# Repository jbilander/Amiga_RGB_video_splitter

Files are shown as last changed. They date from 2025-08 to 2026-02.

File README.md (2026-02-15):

# Amiga_RGB_video_splitter
Extend your amiga RGB video signal to two display units - screens, monitors, etc, simultaneously

BOM Rev. C
---------
Reference  | Name/Value   | Package/Footprint | Notes
-|-|-|-|
U1 | THS7374IPWR | TSSOP-14_4.4x5mm_P0.65mm | [THS7374IPWR](https://www.mouser.com/ProductDetail/595-THS7374IPWR)
U2 | 74HCT2G17 | TSOP-6_1.65x3.05mm_P0.95mm | [HCT2G17GV125](https://www.mouser.com/ProductDetail/771-HCT2G17GV125)
U3 | 74HCT2G14 | TSOP-6_1.65x3.05mm_P0.95mm | [HCT2G14GV125](https://www.mouser.com/ProductDetail/771-HCT2G14GV125)
U4 | 74LVC1GX04GV X-TAL DRIVER | TSOP-6_1.65x3.05mm_P0.95mm | [LVC1GX04GV125](https://www.mouser.com/ProductDetail/771-LVC1GX04GV125)
Y1 | 18pF Crystal 28.6363 MHz (NTSC) or 28.375 MHz (PAL) | 3.2 mm x 2.5 mm | [ECS-286.3-18-33-JEM-TR](https://www.mouser.com/ProductDetail/520-286.3-18-33-JEMT) (NTSC)<br /> [ABM8-28.375MHZ-B2-T](https://www.mouser.com/ProductDetail/815-ABM8-28.375-B2-T) (PAL)
J1 | D-SUB DB23| DB23_Female-Connector | [Female 23 PIN DB23](https://www.aliexpress.com/item/1005007020706331.html)
J2 | DSUB-15-HD | HD_Female_Horizontal | [VGA connector](https://www.aliexpress.com/item/1005007383371077.html)
J3 | 9 Pin Mini Din Connector | Right Angle TH Mini Circular DIN Receptacle | [9pin Mini Din](https://www.aliexpress.com/item/1005005737270650.html)
J4 | PJ-320A | DIP 3.5mm Headphone Audio Socket 4Pins Audio interface | [PJ-320A](https://www.aliexpress.com/item/4000661212458.html)
J5 | MSK12D19 | 3Pin Slide Toggle Switch Pitch_2.5mm | [MSK12D19 SMD](https://www.aliexpress.com/item/1005006482584650.html)
J6 | MSK12D19 | 3Pin Slide Toggle Switch Pitch_2.5mm | [MSK12D19 SMD](https://www.aliexpress.com/item/1005006482584650.html)
J7 | Right angle Single-Pin Header | 0.64 mm square pin angled | pin for a flylead back to switchable Agnus pin 41 (or its pad on motherboard, e.g. JP4 on A500 Rev.6A)
JP1 | Solder_Jumper | | Solder Jumper for setting above pin (J7) to either /XCLKEN or OE-signal (inverted /XCLKEN signal).
C1 | 100uF Radial Pitch_2.5mm | Capacitor TH Radial_D5.0mm_P2.50mm | e.g. <br />[ECA-1AM101](https://www.mouser.com/ProductDetail/667-ECE-A0JKA101I) <br />[ECE-A0JKA101I](https://www.mouser.com/ProductDetail/667-ECA-1AM101) <br />Bend down flush to board before soldering
C2-C6 | Ceramic Capacitor 0.1uF = 100nF | 0805 | e.g. [CL21B104KACNFNC](https://www.mouser.com/ProductDetail/187-CL21B104KACNFNC)
C7-C8 | Multilayer Ceramic Capacitors MLCC - 32pF | 0603 | [06031A320FAT2A ](https://www.mouser.com/ProductDetail/581-06031A320FAT2A) for oscillator circuit
RN1-RN2 | 75 Ω RES ARRAY 4 Resistors | 1206 | [CAT16-75R0F4LF](https://www.mouser.com/ProductDetail/652-CAT16-75R0F4LF)
R1 | 330 Ω | 1206 | Series resistor on C-sync line
R2-R4 | 10k Ω | 1206  
R5 | Resistor 2.2M Ω | 0603 | Resistor in oscillator-circuit
R6 | Resistor 1k Ω | 0603 | Resistor in oscillator-circuit
R7 | Resistor 150 Ω | 1206 | Damping resistor for XCLK out to minimize reflections and ringing
Housing | 2 x Plastic Shell Cover | For DB23/DB25 plug | [Aliexpress](https://www.aliexpress.com/item/1005004717091904.html)
4 x PinHeader | PinHeader Board Weight/Level Support | 3-pin 2.54 mm pitch single row | Move the plastic guard to leave ~7.5 mm of pin before soldering in order to hold board in perfect level inside the housing

***

<a href="images/Amiga_RGB_video_splitter_pic1.png">
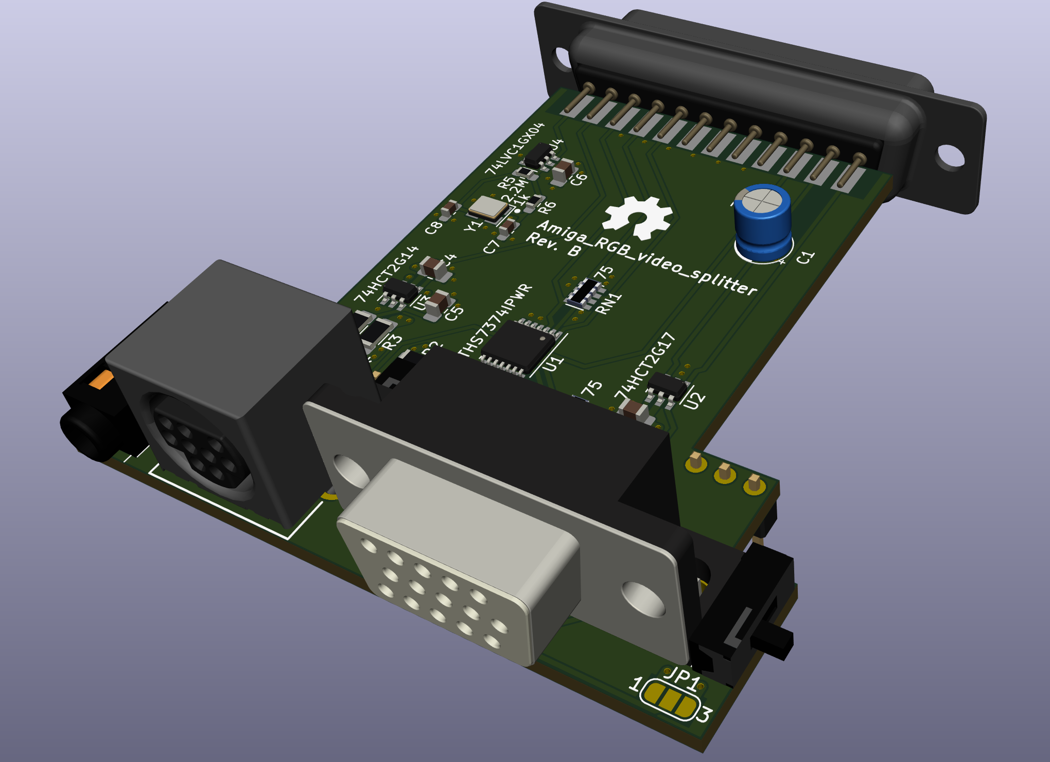
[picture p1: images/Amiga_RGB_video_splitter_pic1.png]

</a>

***

If you use jumper-wire from JP1-pin then you bridge it either with the left pad or the right pad depending on your setup:

    1. Motherboard has PAL oscillator and Adapter has NTSC oscillator = bridge JP1-pin with XCLKEN-pad (PAD 1)
    2. Motherboard has NTSC oscillator and Adapter has PAL oscillator = bridge JP1-pin with OE-pad (PAD 3)

Please note, using a jumper-wire is completely optional, You can switch ECS Agnus in Early Startup menu or with software such as Degrader and then you only control the external XLCK-crystal enable or disable via the switch on the adaptor. However it can be more convenient to have both tasks controlled from one single switch, hence connecting a jumper-wire.

***

<a href="images/SEGA_Mega_Drive_2_SCART_lead_pic1.jpg">
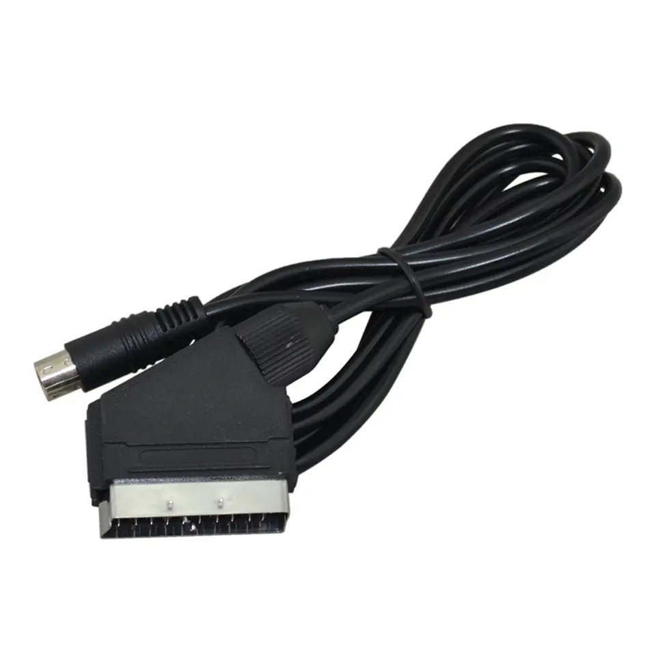
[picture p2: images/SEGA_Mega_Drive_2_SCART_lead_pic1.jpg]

</a>
<a href="images/SEGA_Mega_Drive_2_SCART_lead_wiring.jpg">
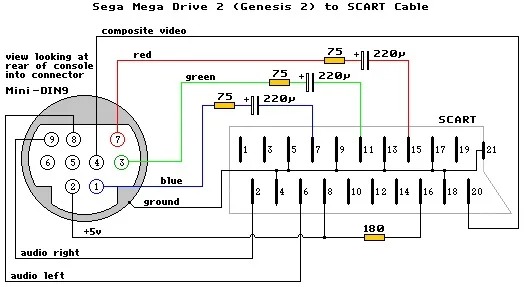
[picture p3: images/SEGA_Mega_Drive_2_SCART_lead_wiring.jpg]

</a>
<br />
<a href="images/SEGA_Mega_Drive_2_SCART_lead_pic2.jpg">
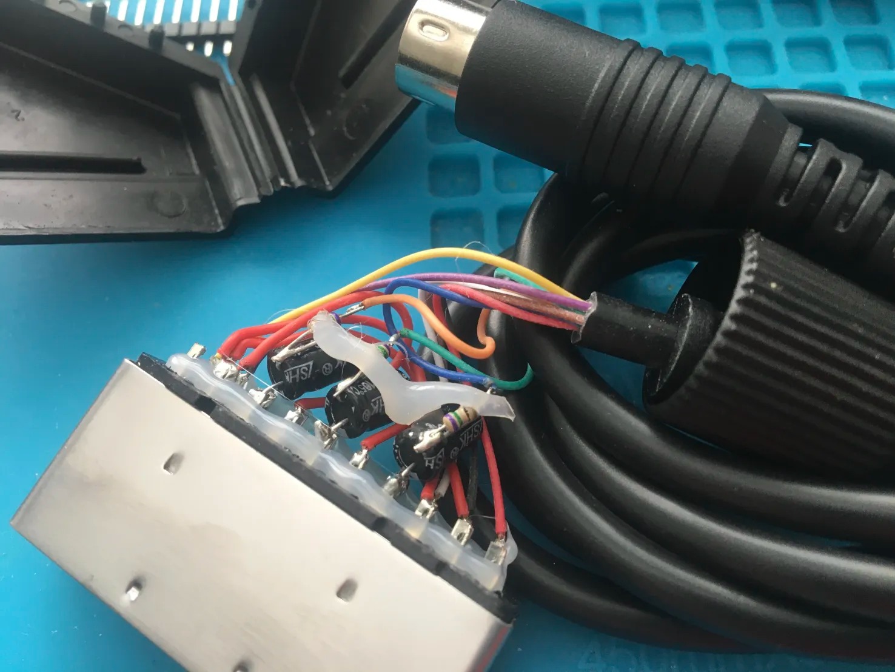
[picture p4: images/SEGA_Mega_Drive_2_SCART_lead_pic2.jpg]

</a>
<a href="images/SEGA_Mega_Drive_2_SCART_lead_pic3.jpg">
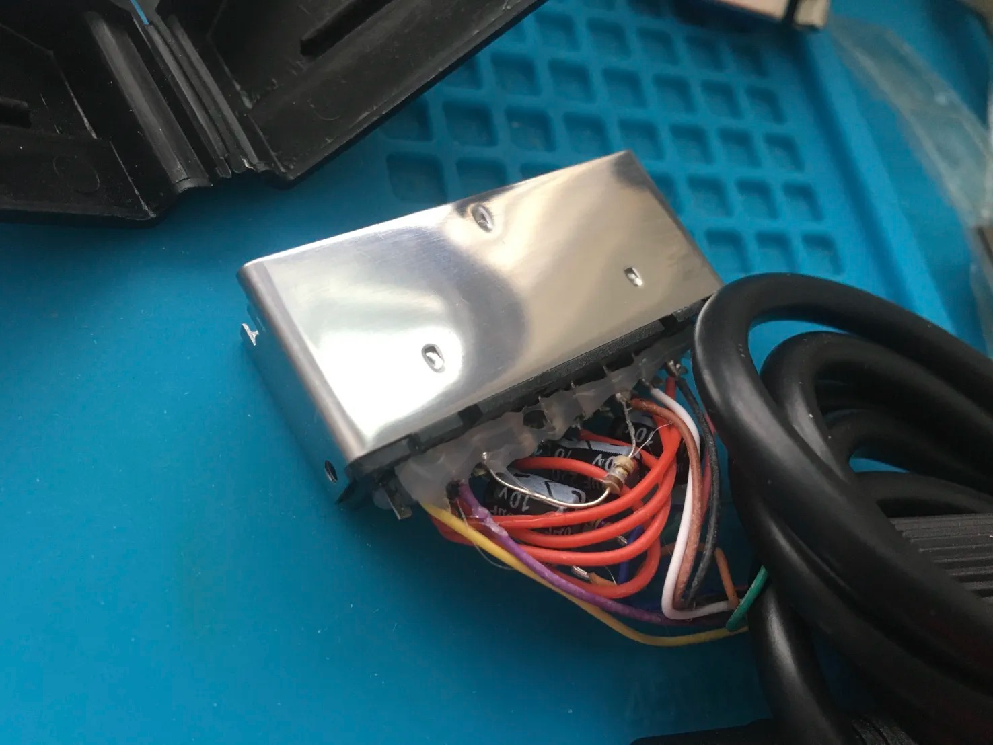
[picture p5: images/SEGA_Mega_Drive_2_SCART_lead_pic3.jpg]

</a>

Suitable SCART-lead to use with the adapter (originally for the SEGA Mega Drive 2, (Genesis 2) with AC coupling inside) <br />
https://www.aliexpress.com/item/1005007360209844.html

***

<a href="images/Amiga_RGB_video_splitter_pic2.jpg">
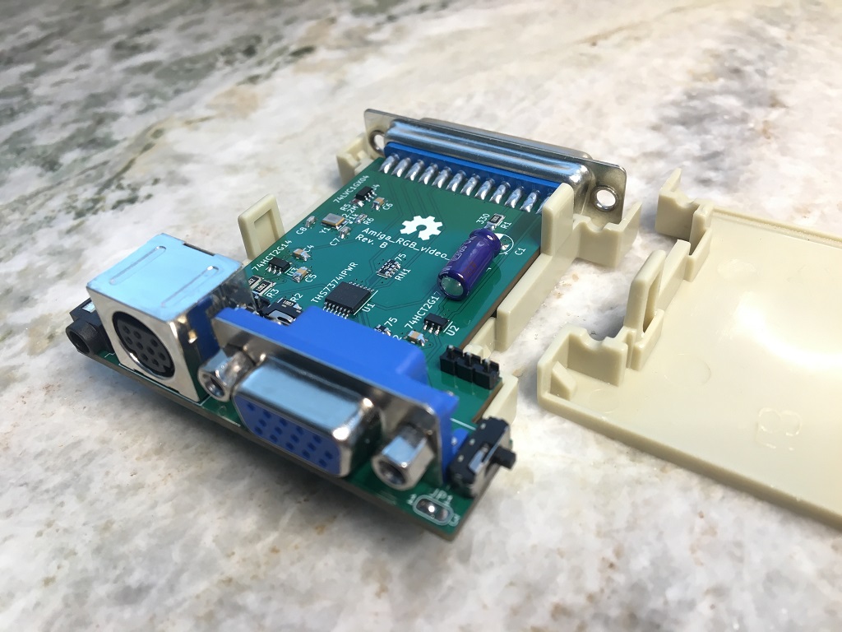
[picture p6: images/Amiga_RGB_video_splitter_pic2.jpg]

</a>
<a href="images/Amiga_RGB_video_splitter_pic3.jpg">
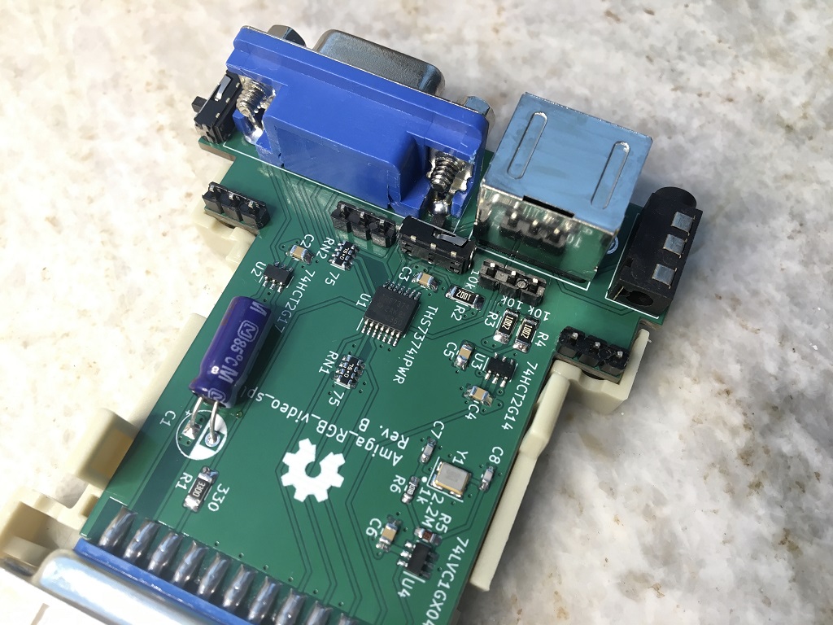
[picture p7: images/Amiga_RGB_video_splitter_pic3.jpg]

</a>
<a href="images/Amiga_RGB_video_splitter_pic4.jpg">
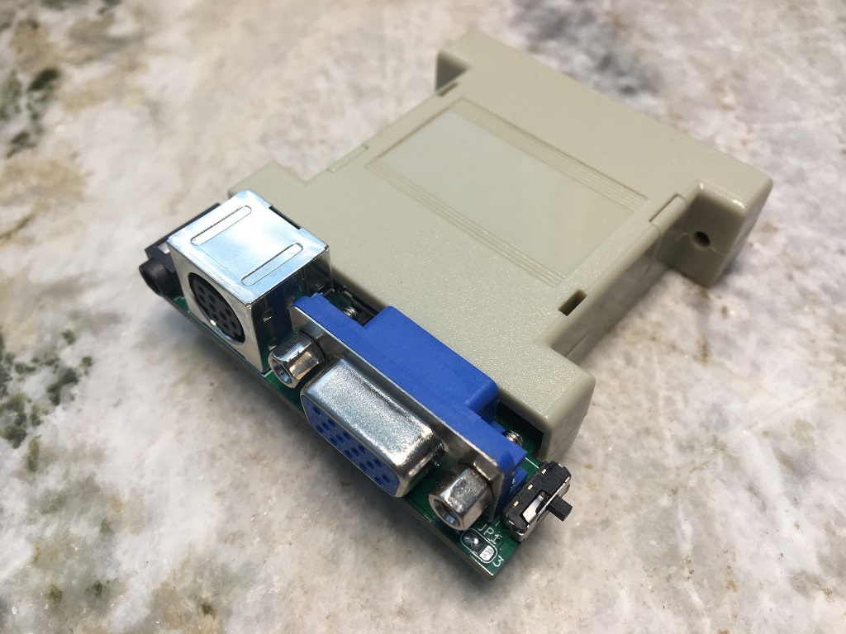
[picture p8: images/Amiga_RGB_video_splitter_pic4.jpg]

</a>
<br />
<a href="images/Amiga_RGB_video_splitter_pic5.jpg">
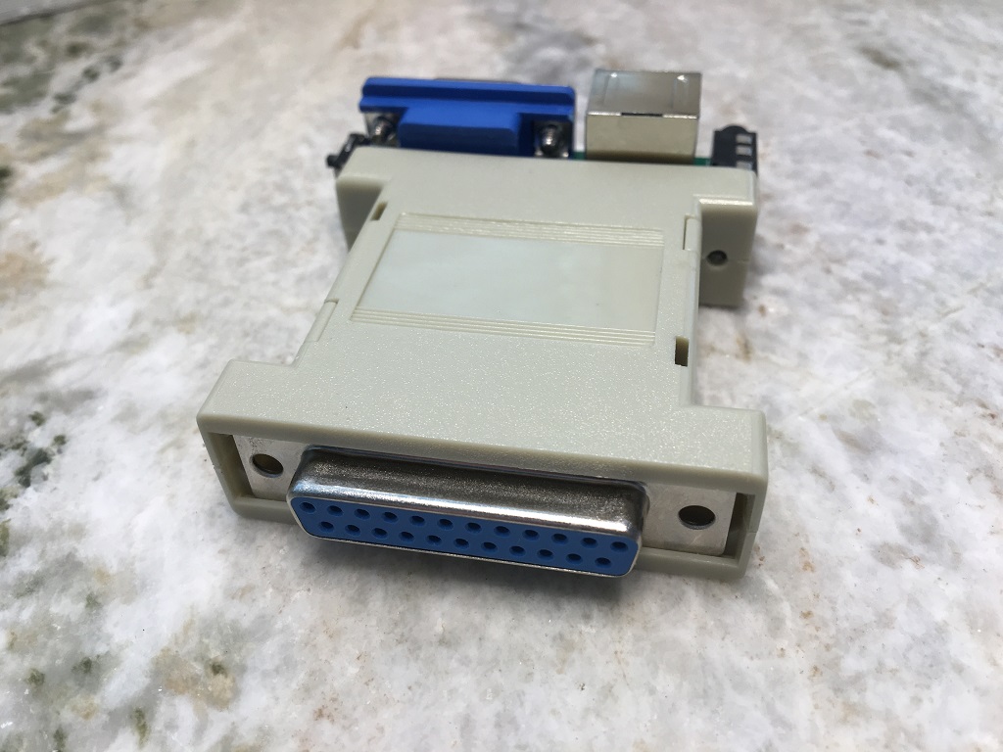
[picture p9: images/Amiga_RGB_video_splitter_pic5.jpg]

</a>
<a href="images/Amiga_RGB_video_splitter_pic6.jpg">
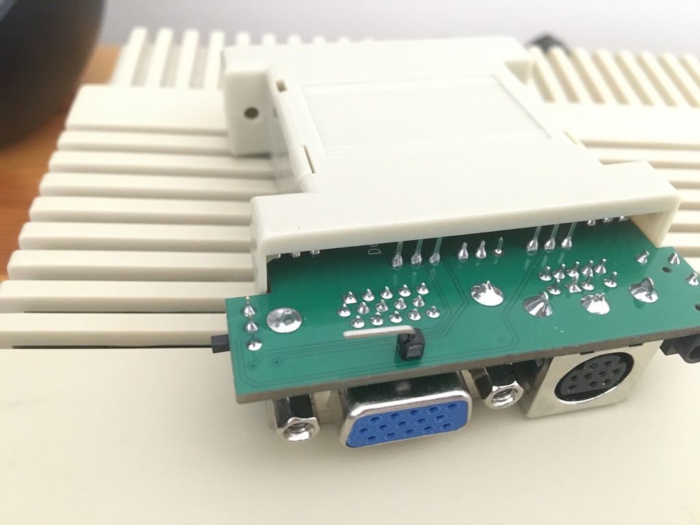
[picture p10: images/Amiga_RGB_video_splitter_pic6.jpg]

</a>
<a href="images/Amiga_RGB_video_splitter_pic7.jpg">
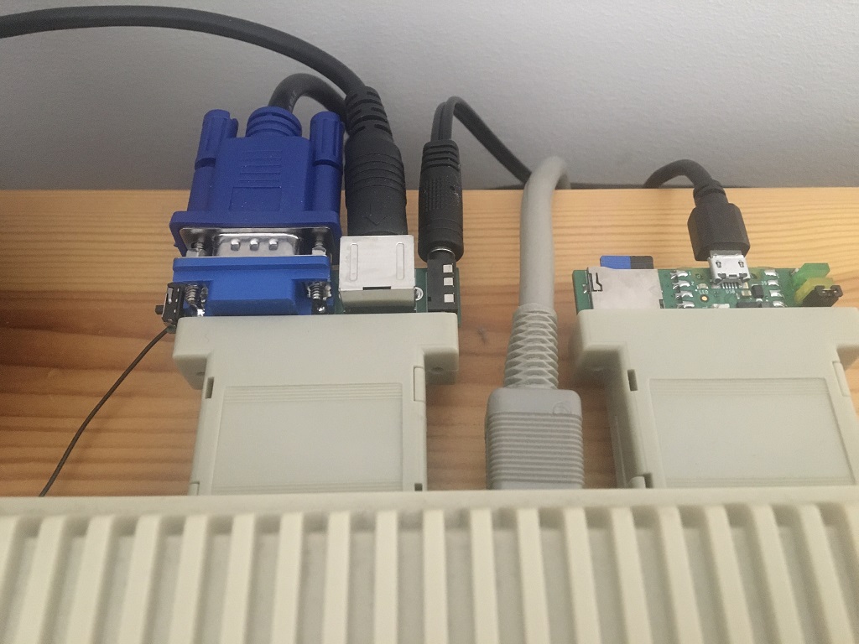
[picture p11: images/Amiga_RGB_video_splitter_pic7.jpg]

</a>
<br />
<a href="images/Amiga_RGB_video_splitter_PCBs.jpg">
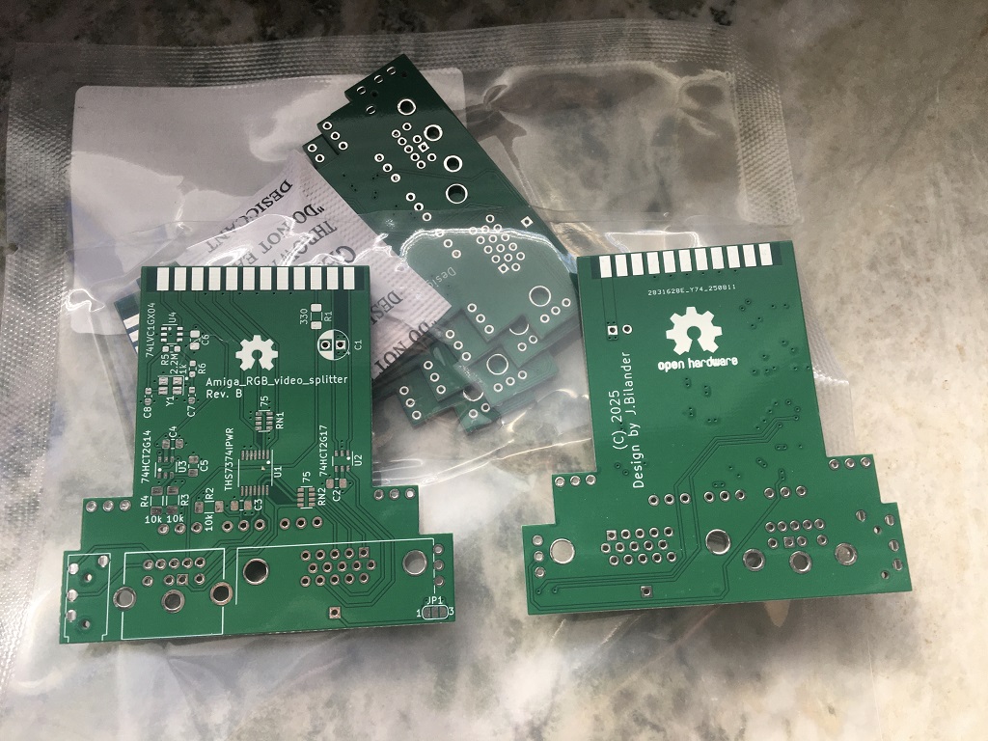
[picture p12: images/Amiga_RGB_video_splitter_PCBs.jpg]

</a>
<a href="images/Jumper_wire_to_JP4_pad.jpg">
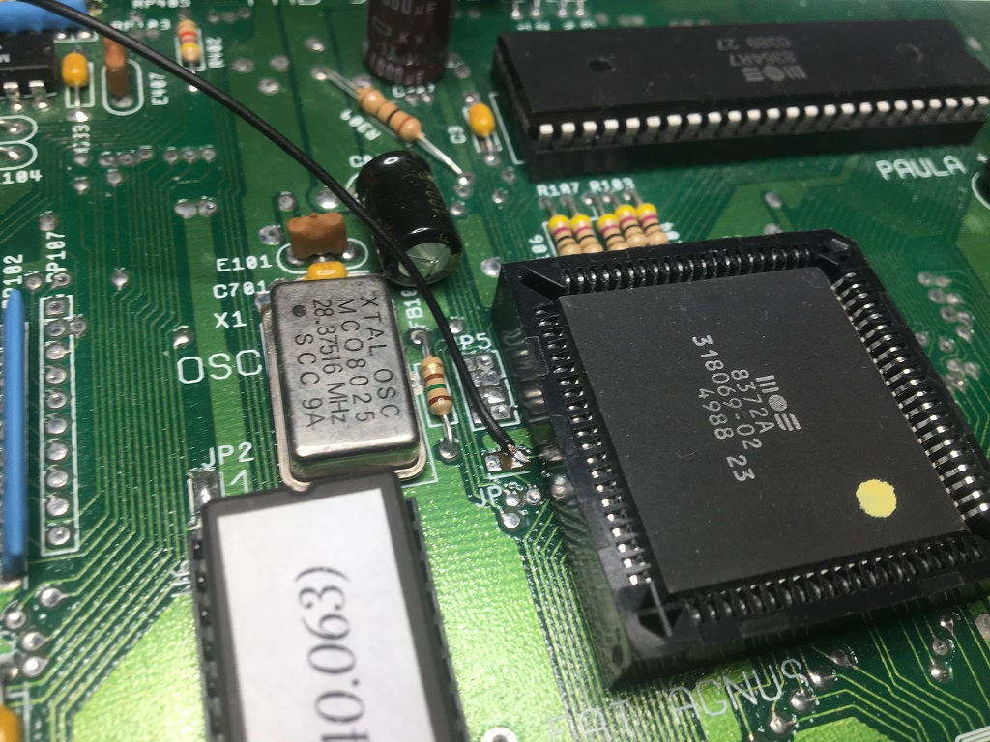
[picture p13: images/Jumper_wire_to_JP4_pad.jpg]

</a>
<br />
<a href="images/Amiga_RGB_video_splitter_filterOff.jpg">
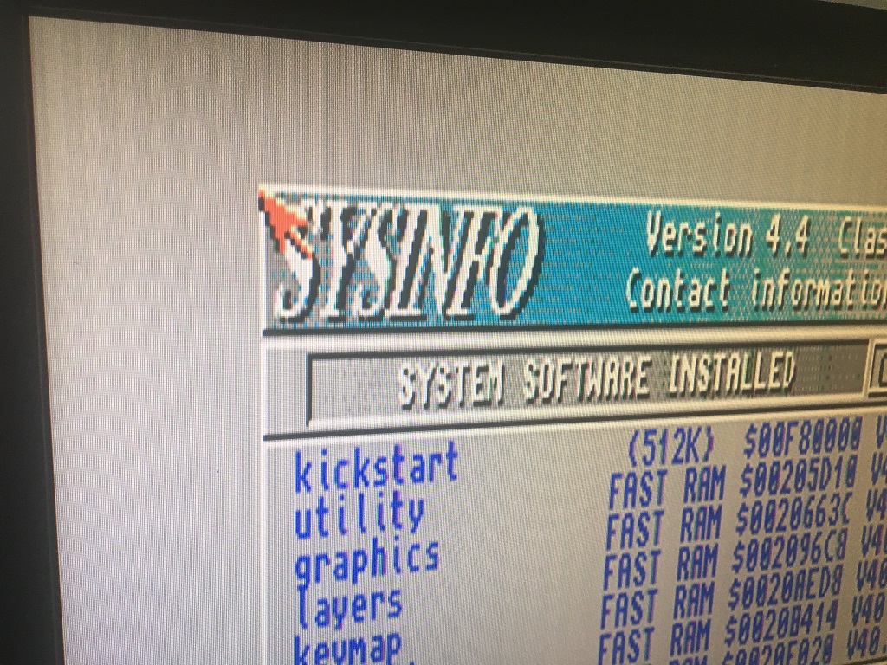
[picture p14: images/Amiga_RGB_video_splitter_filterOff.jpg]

</a>
<a href="images/Amiga_RGB_video_splitter_filterOn.jpg">
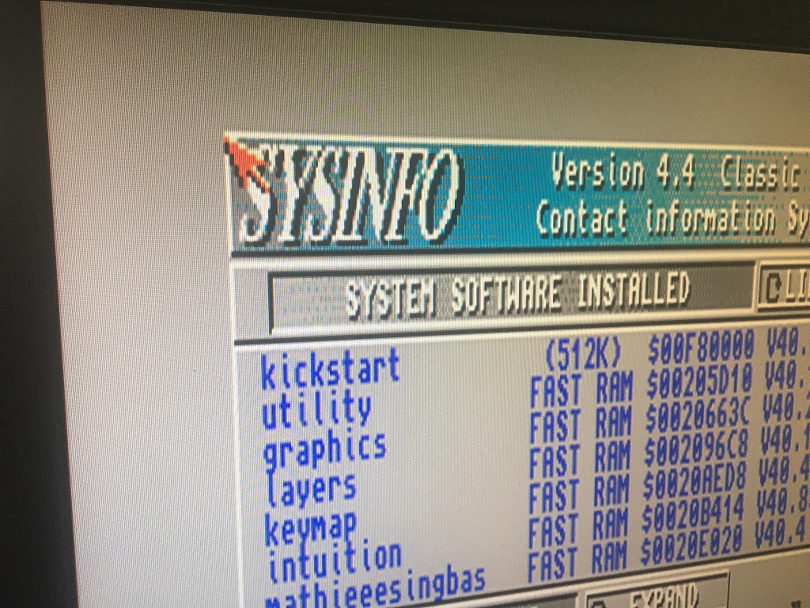
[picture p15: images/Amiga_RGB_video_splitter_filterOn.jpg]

</a>
<br />
Filter OFF vs. Filter ON<br />
With the THS7374's filter activated you can clearly see that the vertical jailbars are gone (right picture).

***

When ordering from JLCPCB select:

Specify Layer Sequence: Yes

    L1(Top layer):    F_Cu.gbr
    L2(Inner layer1): GND_Cu.gbr
    L3(Inner layer2): VCC_Cu.gbr
    L4(Bottom layer): B_Cu.gbr

Remove Order Number: 

    Specify a location

This will notify JLC where to put the order number, they will replace the "JLCJLCJLCJLC" silkscreen label.

***

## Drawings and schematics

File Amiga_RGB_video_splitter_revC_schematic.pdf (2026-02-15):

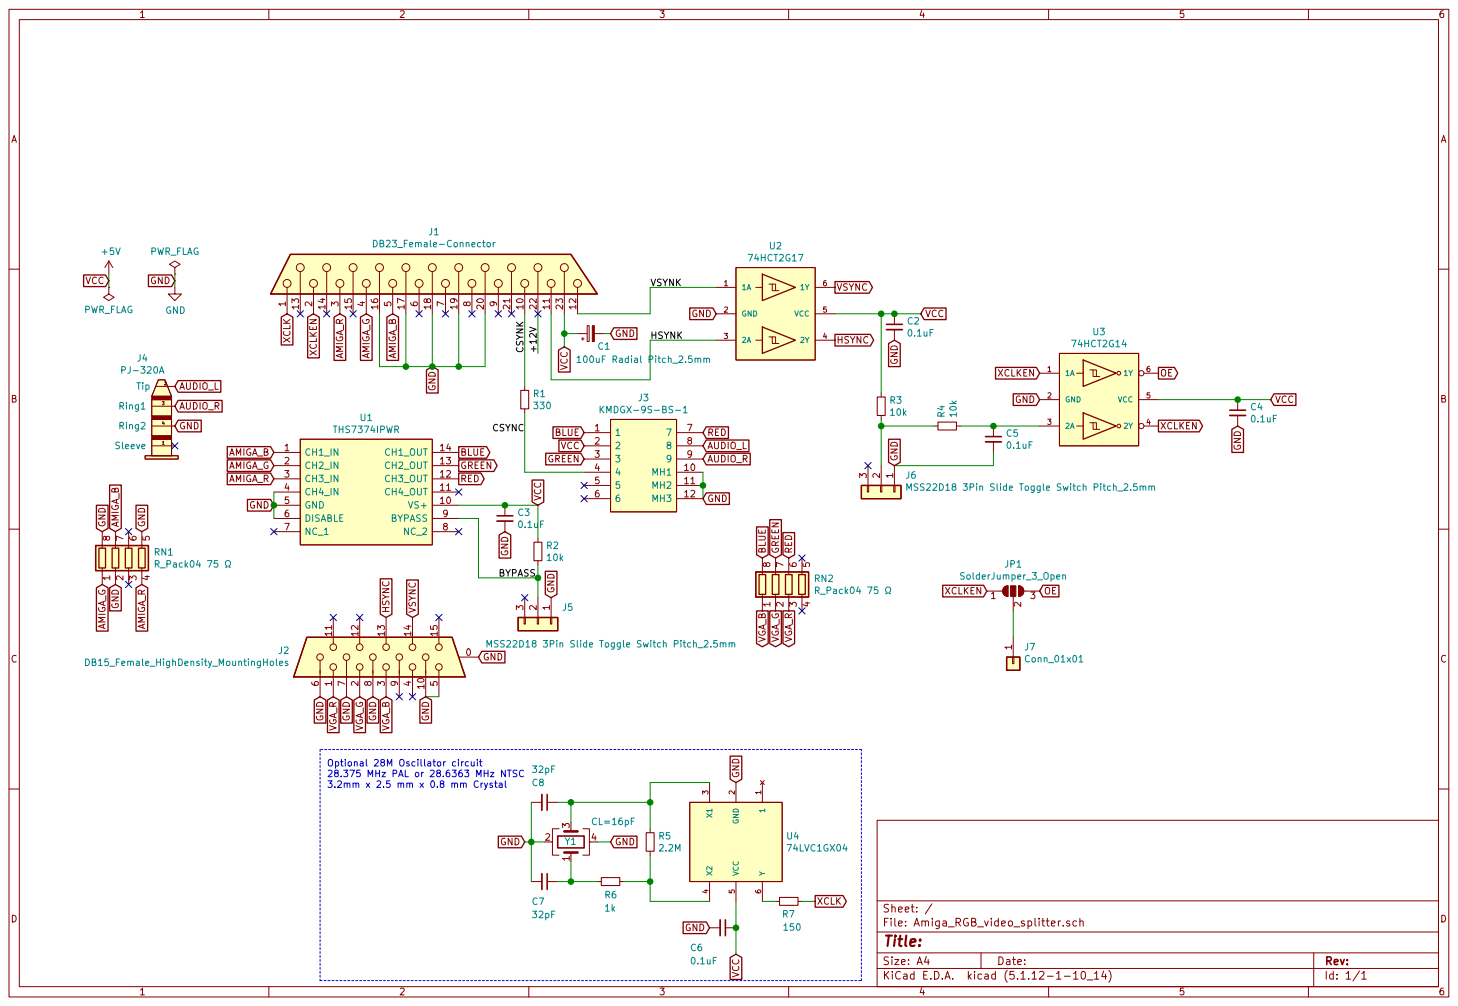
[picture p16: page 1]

BYPASS Optional 28M Oscillator circuit 28.375 MHz PAL or 28.6363 MHz NTSC

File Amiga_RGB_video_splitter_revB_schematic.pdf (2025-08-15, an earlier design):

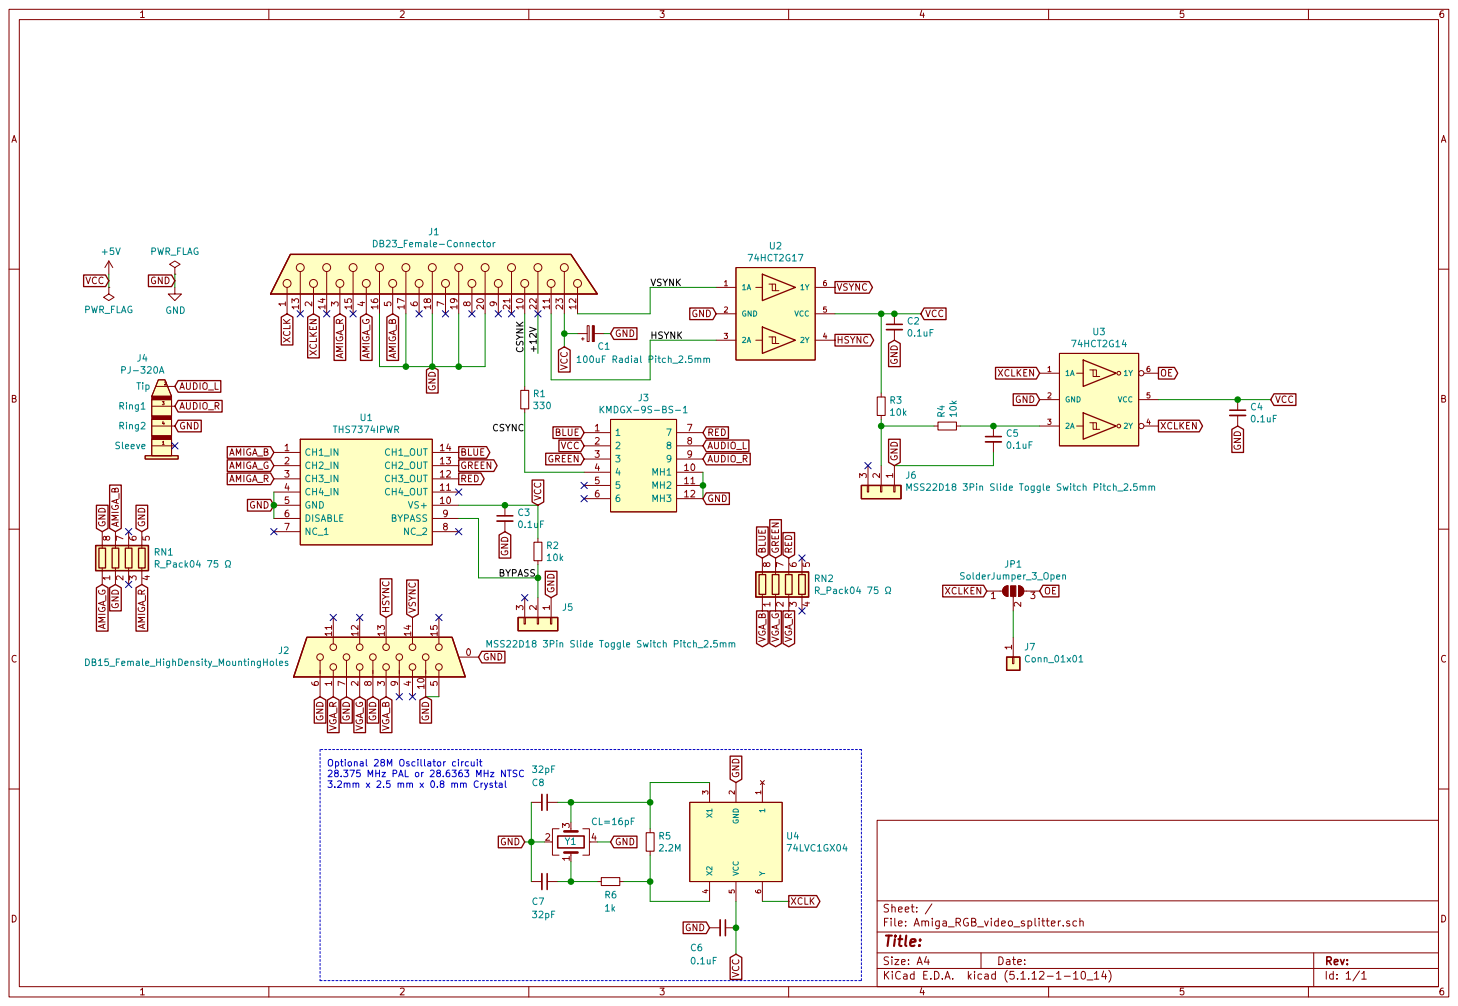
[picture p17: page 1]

BYPASS Optional 28M Oscillator circuit 28.375 MHz PAL or 28.6363 MHz NTSC

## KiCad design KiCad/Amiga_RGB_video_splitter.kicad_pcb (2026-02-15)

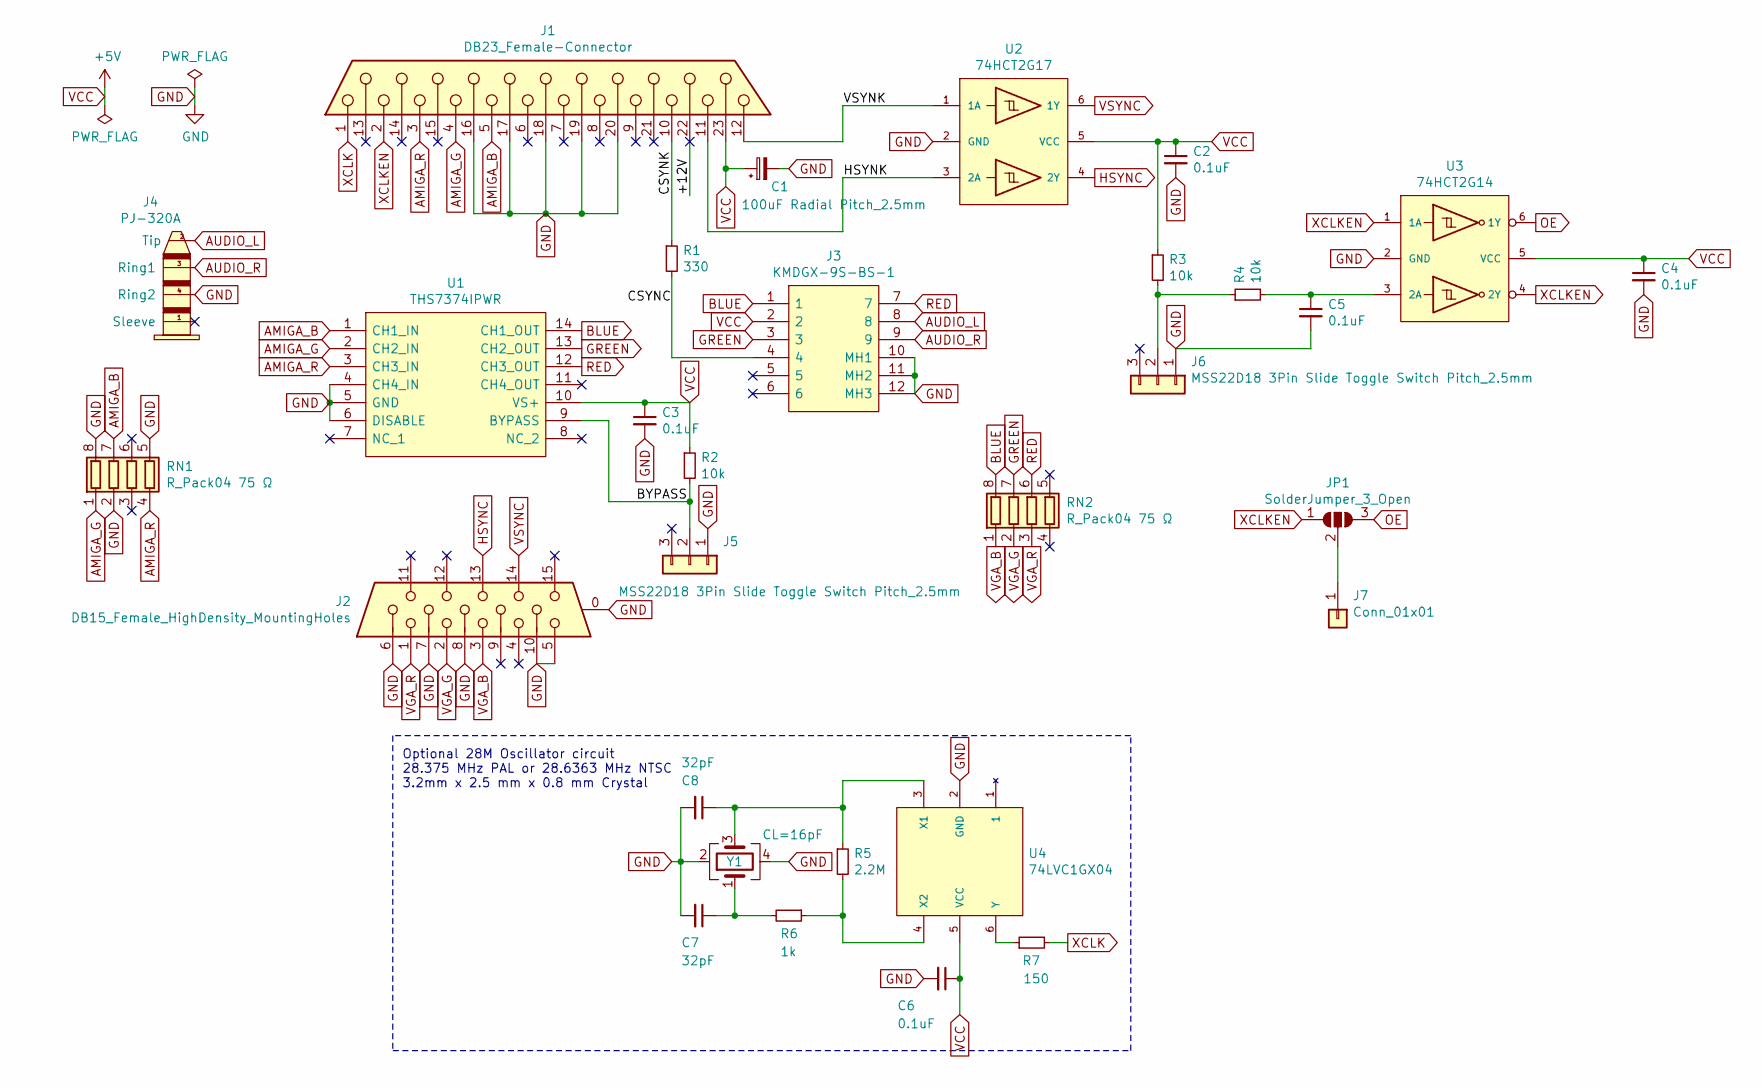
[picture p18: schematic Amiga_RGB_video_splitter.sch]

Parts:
C1: 100uF Radial Pitch_2.5mm; CP_Radial_D5.0mm_P2.50mm
C2, C3, C4, C5, C6: 0.1uF; C_0805_2012Metric_Pad1.18x1.45mm_HandSolder
C7, C8: 32pF; C_0603_1608Metric_Pad1.08x0.95mm_HandSolder
J1: DB23_Female-Connector; DSUB-23_Female_EdgeMount_P2.77mm
J2: DB15_Female_HighDensity_MountingHoles; DSUB-15-HD_Female_Horizontal_P2.29x1.98mm_EdgePinOffset3.03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
J3: KMDGX-9S-BS-1; KMDGX9SBS1
J4: PJ-320A
J5, J6: MSS22D18 3Pin Slide Toggle Switch Pitch_2.5mm; PinHeader_1x03_P2.5mm_Vertical
J7: Conn_01x01; PinHeader_1x01_P2.54mm_Vertical
JP1: SolderJumper_3_Open; SolderJumper-3_P1.3mm_Open_RoundedPad1.0x1.5mm_NumberLabels
R1: 330; R_1206_3216Metric_Pad1.30x1.75mm_HandSolder
R2, R3, R4: 10k; R_1206_3216Metric_Pad1.30x1.75mm_HandSolder
R5: 2.2M; R_0603_1608Metric_Pad0.98x0.95mm_HandSolder
R6: 1k; R_0603_1608Metric_Pad0.98x0.95mm_HandSolder
R7: 150; R_1206_3216Metric_Pad1.30x1.75mm_HandSolder
RN1, RN2: R_Pack04 75 Ω; RESCAF80P320X160X60-8N
U1: THS7374IPWR; TSSOP-14_4.4x5mm_P0.65mm
U2: 74HCT2G17; TSOP-6_1.65x3.05mm_P0.95mm
U3: 74HCT2G14; TSOP-6_1.65x3.05mm_P0.95mm
U4: 74LVC1GX04; TSOP-6_1.65x3.05mm_P0.95mm
Y1: CL=16pF; Crystal_SMD_SeikoEpson_FA238-4Pin_3.2x2.5mm

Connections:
/+12V: J1.22
/BYPASS: J5.2, R2.2, U1.9 (BYPASS)
/CSYNC: J3.4, R1.2
/CSYNK: J1.10, R1.1
/HSYNK: J1.11, U2.3 (2A)
/VSYNK: J1.12, U2.1 (1A)
AMIGA_B: J1.5, RN1.7 (R2.2), U1.1 (CH1_IN)
AMIGA_G: J1.4, RN1.1 (R1.1), U1.2 (CH2_IN)
AMIGA_R: J1.3, RN1.4 (R4.1), U1.3 (CH3_IN)
AUDIO_L: J3.8, J4.2 (Tip)
AUDIO_R: J3.9, J4.3 (Ring1)
BLUE: J3.1, RN2.8 (R1.2), U1.14 (CH1_OUT)
GND: C1.2, C2.2, C3.2, C4.2, C5.2, C6.2, C7.2, C8.2, J1.16, J1.17, J1.18, J1.19, J1.20, J2.0, J2.5, J2.6, J2.7, J2.8, J2.10, J3.10 (MH1), J3.11 (MH2), J3.12 (MH3), J4.4 (Ring2), J5.1, J6.1, RN1.2 (R2.1), RN1.5 (R4.2), RN1.8 (R1.2), U1.4 (CH4_IN), U1.5 (GND), U1.6 (DISABLE), U2.2 (GND), U3.2 (GND), U4.2 (GND), Y1.2, Y1.4
GREEN: J3.3, RN2.7 (R2.2), U1.13 (CH2_OUT)
HSYNC: J2.13, U2.4 (2Y)
unnamed: C5.1, R4.2, U3.3 (2A)
unnamed: C7.1, R6.2, Y1.1
unnamed: C8.1, R5.1, U4.3 (X1), Y1.3
unnamed: J6.2, R3.2, R4.1
unnamed: J7.1, JP1.2 (C)
unnamed: R5.2, R6.1, U4.4 (X2)
unnamed: R7.1, U4.6 (Y)
OE: JP1.3 (B), U3.6 (1Y)
RED: J3.7, RN2.6 (R3.2), U1.12 (CH3_OUT)
VCC: C1.1, C2.1, C3.1, C4.1, C6.1, J1.23, J3.2, R2.1, R3.1, U1.10 (VS+), U2.5 (VCC), U3.5 (VCC), U4.5 (VCC)
VGA_B: J2.3, RN2.1 (R1.1)
VGA_G: J2.2, RN2.2 (R2.1)
VGA_R: J2.1, RN2.3 (R3.1)
VSYNC: J2.14, U2.6 (1Y)
XCLK: J1.1, R7.2
XCLKEN: J1.2, JP1.1 (A), U3.1 (1A), U3.4 (2Y)

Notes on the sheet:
Optional 28M Oscillator circuit 28.375 MHz PAL or 28.6363 MHz NTSC 3.2mm x 2.5 mm x 0.8 mm Crystal

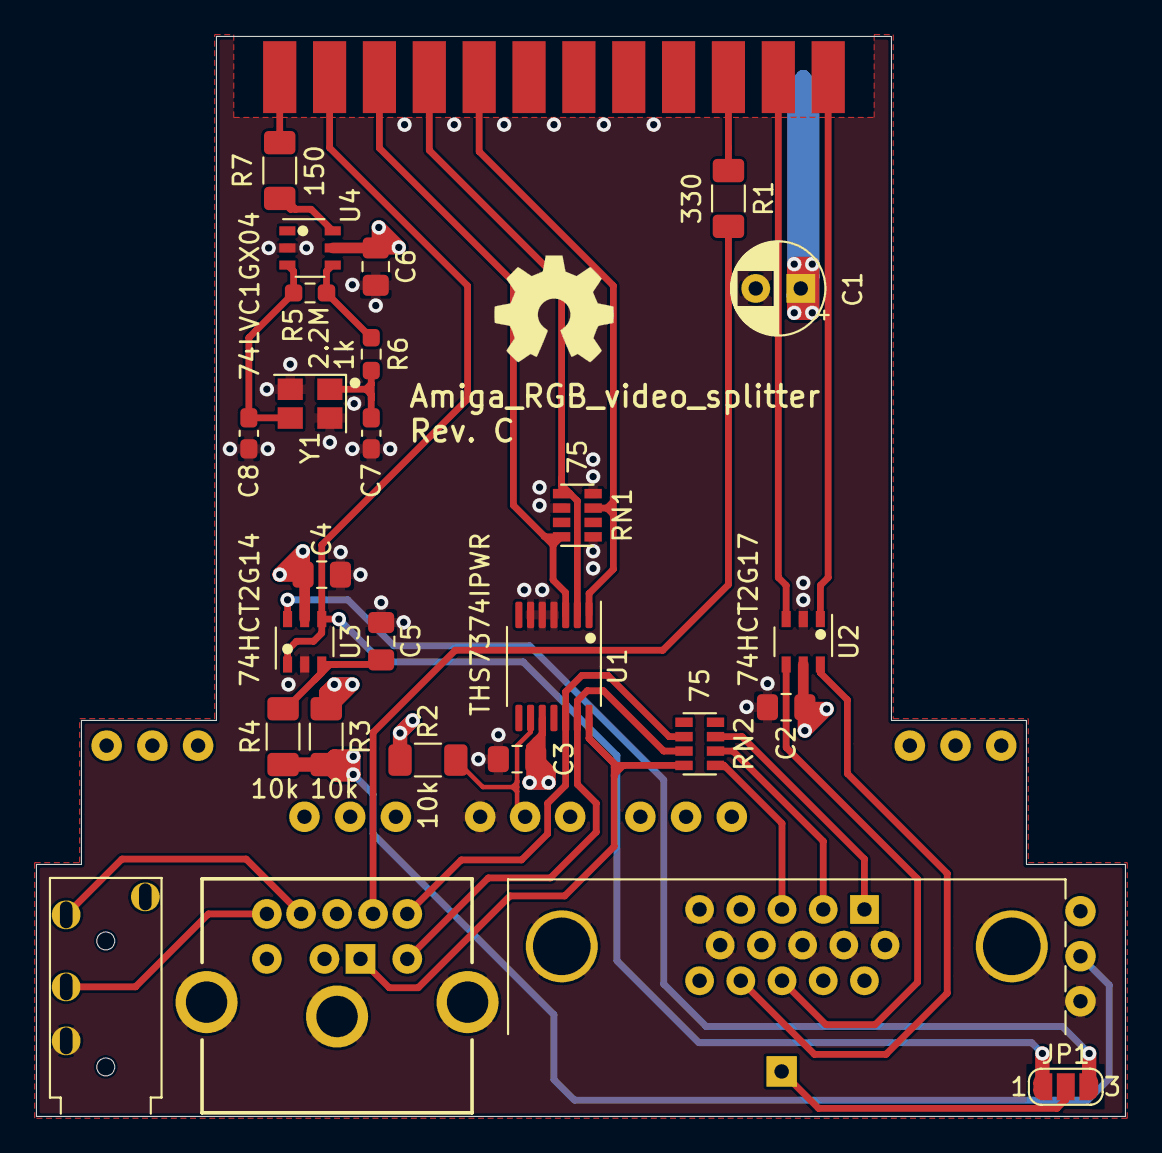
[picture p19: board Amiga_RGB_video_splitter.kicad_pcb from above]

Board: 4 copper layers, 60.5 x 60.0 mm, 30 parts (1 on the bottom side), 30 nets.

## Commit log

2025-05-19 Add footprint
2025-05-19 Add kicad files
    [Amiga_RGB_video_splitter.kicad_pcb, Amiga_RGB_video_splitter.sch]
2025-05-19 Add symbol and place footprint for Connector_DB15_Female_HighDensity_MountingHoles
    [Amiga_RGB_video_splitter.kicad_pcb, Amiga_RGB_video_splitter.sch]
2025-05-19 Add Mini DIN 9 position receptacle connector
    [Amiga_RGB_video_splitter.kicad_pcb, Amiga_RGB_video_splitter.sch]
2025-05-19 Add 3D-model of Mini DIN 9 position receptacle connector
2025-05-19 Change 3D-model for Mini DIN 9 connector to KMDGX-9S-BS-1_A1.stp
    [Amiga_RGB_video_splitter.kicad_pcb]
2025-05-23 Add footprint for PJ-320A
2025-05-23 Add a PJ-320A stereo input connector to the design
    [Amiga_RGB_video_splitter.kicad_pcb, Amiga_RGB_video_splitter.sch]
2025-05-23 Add THS7374IPWR to the design and temporary routing
    [Amiga_RGB_video_splitter.kicad_pcb, Amiga_RGB_video_splitter.sch]
2025-05-23 Add footprint for THS7374IPWR
2025-05-23 Add capacitor and route VCC to pin 10 on U1, add resistor R1 to Csync line
    [Amiga_RGB_video_splitter.kicad_pcb, Amiga_RGB_video_splitter.sch]
2025-05-23 Add 75 Ω termination for RGB lines with resistor pack RN1
    [Amiga_RGB_video_splitter.kicad_pcb, Amiga_RGB_video_splitter.sch]
2025-05-23 Add series resistor for VGA RGB lines with resistor pack RN2
    [Amiga_RGB_video_splitter.kicad_pcb, Amiga_RGB_video_splitter.sch]
2025-05-26 Add U2 (74HCT2G17) in TSOP-6 to the design for V-sync and H-sync buffering
    [Amiga_RGB_video_splitter.kicad_pcb, Amiga_RGB_video_splitter.sch]
2025-05-26 Silkscreen fix on footprint
2025-05-26 Change C1 to C2 and C2 to C3 and adding resistor Ohm values on silkscreen
    [Amiga_RGB_video_splitter.kicad_pcb, Amiga_RGB_video_splitter.sch]
2025-05-26 Add polarized TH-capacitor C1 100uF Radial pitch 2.5 mm
    [Amiga_RGB_video_splitter.kicad_pcb, Amiga_RGB_video_splitter.sch]
2025-05-28 Add 10k pull-up resistor R2 for BYPASS signal going to MSS22D18 3-Pin slide toggle switch
    [Amiga_RGB_video_splitter.kicad_pcb, Amiga_RGB_video_splitter.sch]
2025-05-28 Add footprint for MSS22D18 3-Pin slide toggle switch
2025-05-28 Add 3D-model for resistor pack
2025-05-28 Add 3D-model for MSS22D18 3-Pin slide toggle switch
2025-05-28 Add U3 (74HCT2G14) and R3,R4,C4,C5 to the design
    [Amiga_RGB_video_splitter.kicad_pcb, Amiga_RGB_video_splitter.sch]
2025-05-28 Placement of R3,R4,C4,C5 and routing of U3 circuit
    [Amiga_RGB_video_splitter.kicad_pcb]
2025-05-29 Add U4 (74LVC1GX04) to the design
    [Amiga_RGB_video_splitter.kicad_pcb, Amiga_RGB_video_splitter.sch]
2025-05-29 Placement and routing of U4 (74LVC1GX04)
    [Amiga_RGB_video_splitter.kicad_pcb, Amiga_RGB_video_splitter.sch]
2025-05-29 Add Y1 crystal to the design
    [Amiga_RGB_video_splitter.kicad_pcb, Amiga_RGB_video_splitter.sch]
2025-05-30 Add capacitor C7 and C8, and some silkscreen fixes
    [Amiga_RGB_video_splitter.kicad_pcb, Amiga_RGB_video_splitter.sch]
2025-05-30 Add solder jumper JP1 to the design and route signals XCLKEN and OE to it
    [Amiga_RGB_video_splitter.kicad_pcb, Amiga_RGB_video_splitter.sch]
2025-05-30 Update holes to 0.8 mm in diameter
2025-05-30 Add four PinHeader_1x03_P2.54mm for support structure, fix of edge cuts for better fit plastic shells
    [Amiga_RGB_video_splitter.kicad_pcb, Amiga_RGB_video_splitter.sch]
2025-05-30 Add 3D-model of DB23 connector
2025-05-30 Small silkscreen fix
    [Amiga_RGB_video_splitter.kicad_pcb]
2025-05-31 silkscreen fix
    [Amiga_RGB_video_splitter.kicad_pcb]
2025-05-31 Update plot params
    [Amiga_RGB_video_splitter.kicad_pcb]
2025-08-02 Update footprints
2025-08-02 Fix placement of support pinheaders and RN2, some rerouting and silkscreen fixes, bump revision to Rev B
    [Amiga_RGB_video_splitter.kicad_pcb]
2025-08-09 Relocate the PAL/NTSC 3Pin Slide Toggle Switch
    [Amiga_RGB_video_splitter.kicad_pcb]
2025-08-09 Silkscreen fix on VGA connector footprint
    [Amiga_RGB_video_splitter.kicad_pcb]
2025-08-15 Add schematic pdf
2026-02-15 Add damping 150 Ohm series resistor on XCLK out, bump to Rev. C
    [Amiga_RGB_video_splitter.kicad_pcb, Amiga_RGB_video_splitter.sch]
2026-02-15 Add schematic

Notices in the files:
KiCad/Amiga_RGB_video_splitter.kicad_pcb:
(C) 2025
